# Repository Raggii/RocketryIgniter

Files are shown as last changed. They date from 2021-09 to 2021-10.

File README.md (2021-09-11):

# RocketryIgniter
To design and prototype a dual ignition system that can receive commands over UART and CANBUS. The device must be able to receive commands that arm and fire two separate but identical ignition circuits while also outputting its own system status. The design must attempt to be as compact as possible while also allowing for easy debugging.

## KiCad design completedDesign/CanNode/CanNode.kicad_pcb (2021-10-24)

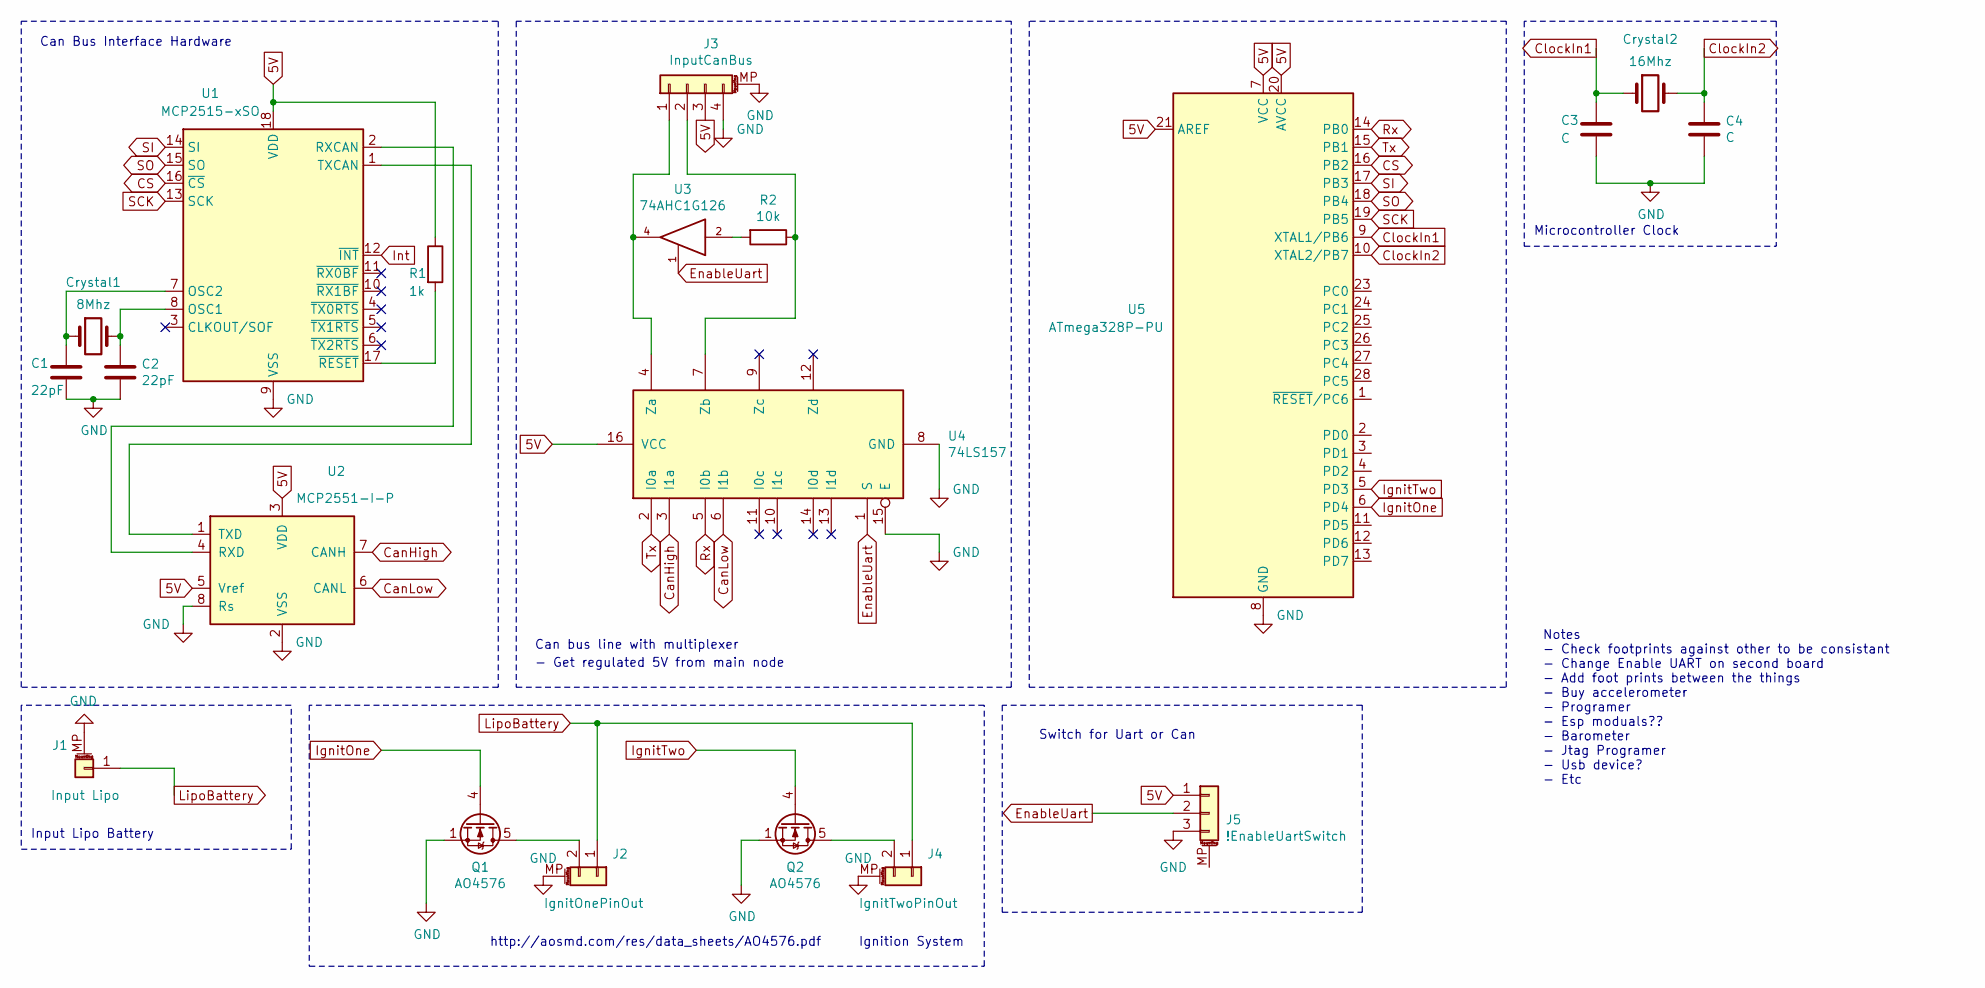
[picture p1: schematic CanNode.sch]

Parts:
C1, C2: 22pF; R_Axial_DIN0204_L3.6mm_D1.6mm_P2.54mm_Vertical
C3, C4: C; R_Axial_DIN0204_L3.6mm_D1.6mm_P2.54mm_Vertical
Crystal1: 8Mhz; Crystal_HC49-4H_Vertical
Crystal2: 16Mhz; Crystal_HC49-4H_Vertical
J1: Input Lipo; PinHeader_1x01_P2.00mm_Vertical
J2: IgnitOnePinOut; PinHeader_1x02_P2.00mm_Vertical
J3: InputCanBus; PinHeader_1x04_P2.00mm_Vertical
J4: IgnitTwoPinOut; PinHeader_1x02_P2.00mm_Vertical
J5: !EnableUartSwitch; PinHeader_1x03_P1.00mm_Vertical
Q1, Q2: AO4576; SOT-23-8_Handsoldering
R1: 1k; R_Axial_DIN0204_L3.6mm_D1.6mm_P5.08mm_Horizontal
R2: 10k; R_Axial_DIN0204_L3.6mm_D1.6mm_P5.08mm_Horizontal
U1: MCP2515-xSO; DIP-18_W7.62mm_LongPads
U2: MCP2551-I-P; DIP-8_W7.62mm
U3: 74AHC1G126; SOT65P210X110-5N
U4: 74LS157; DIP-16_W7.62mm_Socket_LongPads
U5: ATmega328P-PU; DIP-28_W7.62mm

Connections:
5V: J3.3, J5.1, R1.1, U1.18 (VDD), U2.3 (VDD), U2.5 (Vref), U4.16 (VCC), U5.7 (VCC), U5.20 (AVCC), U5.21 (AREF)
CS: U1.16 (~CS), U5.16 (PB2)
CanHigh: U2.7 (CANH), U4.3 (I1a)
CanLow: U2.6 (CANL), U4.6 (I1b)
ClockIn1: C3.1, Crystal2.1, U5.9 (XTAL1/PB6)
ClockIn2: C4.1, Crystal2.2, U5.10 (XTAL2/PB7)
EnableUart: J5.2, U3.1, U4.1 (S)
GND: C1.2, C2.2, C3.2, C4.2, J1.MP (MountPin), J2.MP (MountPin), J3.4, J3.MP (MountPin), J4.MP (MountPin), J5.3, Q1.1 (S), Q1.2 (S), Q1.3 (S), Q2.1 (S), Q2.2 (S), Q2.3 (S), U1.9 (VSS), U2.2 (VSS), U2.8 (Rs), U3.3 (GND), U4.8 (GND), U4.15 (E), U5.8 (GND), U5.22 (GND)
IgnitOne: Q1.4 (G), U5.6 (PD4)
IgnitTwo: Q2.4 (G), U5.5 (PD3)
Int: U1.12 (~INT)
LipoBattery: J1.1, J2.1, J4.1
unnamed: C1.1, Crystal1.1, U1.7 (OSC2)
unnamed: C2.1, Crystal1.2, U1.8 (OSC1)
unnamed: J2.2, Q1.5 (D)
unnamed: J3.1, U3.4, U4.4 (Za)
unnamed: J3.2, R2.1, U4.7 (Zb)
unnamed: J4.2, Q2.5 (D)
unnamed: R1.2, U1.17 (~RESET)
unnamed: R2.2, U3.2
unnamed: U1.1 (TXCAN), U2.1 (TXD)
unnamed: U1.2 (RXCAN), U2.4 (RXD)
Rx: U4.5 (I0b), U5.14 (PB0)
SCK: U1.13 (SCK), U5.19 (PB5)
SI: U1.14 (SI), U5.17 (PB3)
SO: U1.15 (SO), U5.18 (PB4)
Tx: U4.2 (I0a), U5.15 (PB1)
VCC: U3.5 (VCC)

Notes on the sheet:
Can Bus Interface Hardware
Can bus line with multiplexer
- Get regulated 5V from main node
Input Lipo Battery
Ignition System
http://aosmd.com/res/data_sheets/AO4576.pdf
Microcontroller Clock
Notes - Check footprints against other to be consistant - Change Enable UART on second board - Add foot prints between the things - Buy accelerometer - Programer - Esp moduals?? - Barometer - Jtag Programer - Usb device? - Etc
Switch for Uart or Can

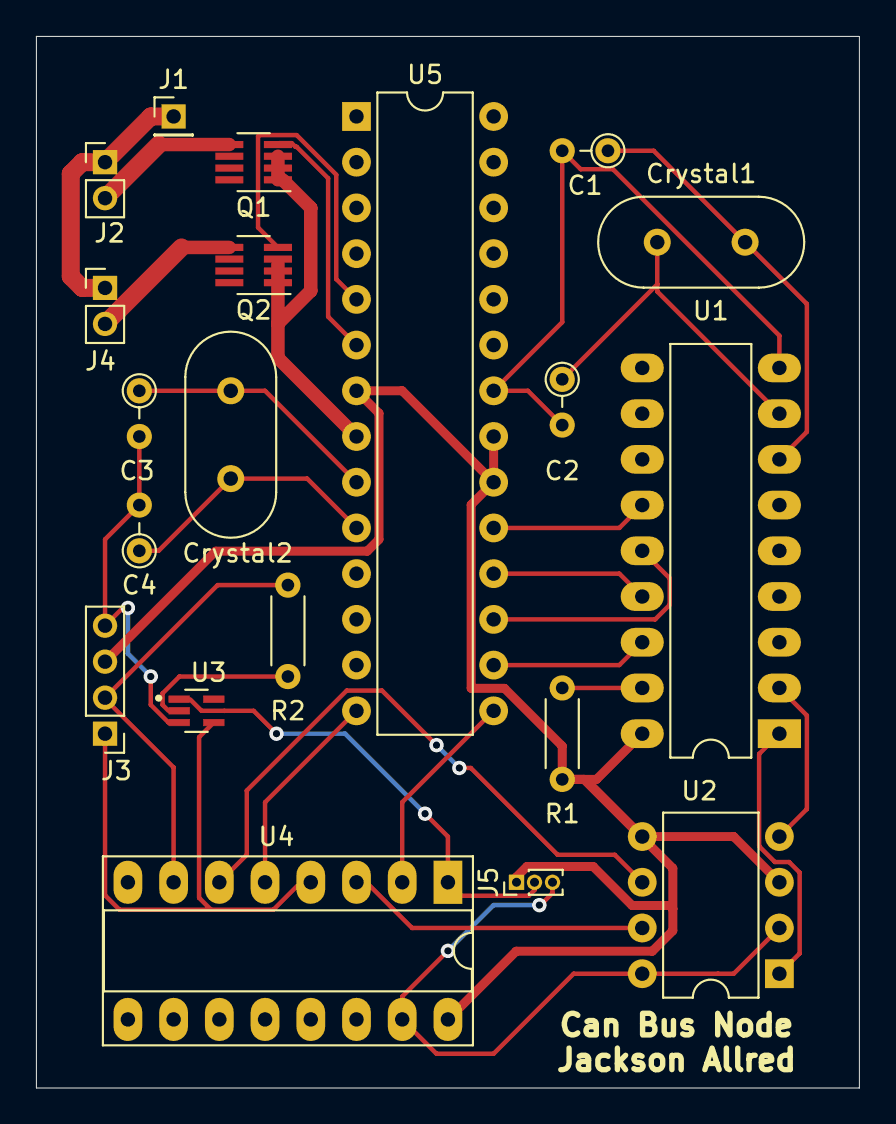
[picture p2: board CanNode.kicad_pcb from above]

Board: 2 copper layers, 45.7 x 58.4 mm, 20 parts (0 on the bottom side), 26 nets.

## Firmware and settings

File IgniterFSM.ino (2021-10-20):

#include <SoftwareSerial.h>

SoftwareSerial softSerial(4,5);

//States for the state machine
#define ERROR -1
#define IDLE 0 
#define ARMED 1
#define FIRING 2 
#define DISABLED 3 
#define LOCKOUT 4
#define TIMEOUT_TEN 10000
#define TIMEOUT_TWO 2000

//Received messages
#define ARM_IGNITER_ONE "01234567"
#define FIRE_IGNITER_ONE "76543210"
#define ARM_IGNITER_TWO "12345678"
#define FIRE_IGNITER_TWO "87654321"

//Pins for matches
#define FIRST_MATCH_PIN 2
#define SECOND_MATCH_PIN 3

//Variables
String receivedMessage;
String stateStringList[] = {"IDLE","ARMED","FIRING","DISABED","LOCKOUT"};

//Igniter variable struct
typedef struct igniterStateMachine {

  int currentState; 
  uint32_t timeOutCounter;
  bool continuity;
  bool arm;
  bool fire;
  int number;
  bool isTimedOut;
  bool stateUpdate;
  
} Igniter;

//Create an Igniter Struct
Igniter* initIgniter(int number){

  Igniter * returnIgniter = (Igniter *)malloc(sizeof(Igniter) * 2);
  returnIgniter->currentState = IDLE;
  returnIgniter->continuity = true;
  returnIgniter->timeOutCounter = 0;
  returnIgniter->arm = false;
  returnIgniter->fire = false;
  returnIgniter->number = number;
  returnIgniter->isTimedOut = false;
  returnIgniter->stateUpdate = false;
  return returnIgniter;
  
}

void serialOutMsg(String message) {

    Serial.println(message);
    softSerial.println(message);
  
}

void printIgniterState(Igniter* igniter){

  String number = String(igniter->number);
  String arm = String(igniter->arm);
  String fire = String(igniter->fire);
  String timeout = String(igniter->isTimedOut);

  Serial.println("Igniter " + number + "\nState is: " + stateStringList[igniter->currentState] + 
                "\nArm Boolean: " + arm + "\nFire Boolean: " + fire + "\nTime Out: " + timeout+ "\n");
  
}

/** Changes the state of the state machine if in IDLE state to ARMED
*   Gets called if armed boolean changes
**/
int armFunction(Igniter* igniter) {
  if(igniter->arm) {
    if(igniter->currentState == IDLE && !igniter->fire)
      igniter->currentState = ARMED;
      //Start 10 Second timer and if fails then sets Arm and Fire to disabled
      igniter->timeOutCounter = millis(); // Snap shot of time when state changed
      
  } else {
     //serialOutMsg("IS NOT TRUE");
     if(igniter->currentState == ARMED){
        igniter->currentState = IDLE;
        //Resets the timer when changes state
        igniter->timeOutCounter = 0;
     }
  }

  return -1;
}
//Changes the state of the state machine if in ARMED state to FIRESTATE
int fireFunction(Igniter* igniter) {

  if(igniter->fire) {
    if(igniter->currentState == ARMED && igniter->arm) {
      igniter->currentState = FIRING;
      //Resets the timer when changes state
      igniter->timeOutCounter = millis();
      
      //Sets pin to Disabled for
      
    } 
  }
 return -1; 
}


/** Changes the state of variables in the Igniter given depending on the message input
 *  Also used to toggle between on and off
 *   returns NULL on fail 
*/
void updateState(String receivedMessage, Igniter* igniter) {
  if(igniter->continuity && !igniter->isTimedOut) {
    if(igniter->number == 1){
      if(receivedMessage == ARM_IGNITER_ONE) {
        //Arming true
        if(igniter->currentState == !LOCKOUT) {
          if(igniter->arm) {
              igniter->arm = false;
              serialOutMsg("First Igniter Arm Pin Deactivated");
          }else {
            igniter->arm = true;
            serialOutMsg("First Igniter Arm Pin Activated"); 
          }
        } else {
           //Is locked out  
            
        }
        igniter->stateUpdate = true;

      }else if(receivedMessage == FIRE_IGNITER_ONE) {
        //Firing true
        if(igniter->fire) {
          igniter->fire = false; 
          serialOutMsg("First Igniter Fire Pin Deactivated");
        } else {
          igniter->fire = true; 
          serialOutMsg("First Igniter Fire Pin Activated");  
        }
        
        igniter->stateUpdate = true;
            
      }  
    }else if(igniter->number == 2){
      if(receivedMessage == ARM_IGNITER_TWO) {
         //Arming true
         if(igniter->arm) {
            igniter->arm = false;
            serialOutMsg("Second Igniter Arm Pin Deactivated");
        }else {
          igniter->arm = true;
          serialOutMsg("Second Igniter Arm Pin Activated"); 
        }
         igniter->stateUpdate = true;
         
       } else if(receivedMessage == FIRE_IGNITER_TWO) {
        //Firing true
        if(igniter->fire) {
          igniter->fire = false; 
          serialOutMsg("Second Igniter Fire Pin Deactivated");
        } else {
          igniter->fire = true; 
          serialOutMsg("Second Igniter Fire Pin Activated");  
        }
        igniter->stateUpdate = true;
       } //else return NULL;
    }
    
  } else {
    //Continuity is not connected so dont update anystate
    if(igniter->isTimedOut) {
        serialOutMsg("Timed out please wait");
    } else {
      serialOutMsg("Continuity check has failed, Please try again");
    }
    
  }
  if(!igniter->arm && !igniter->fire) {
      igniter->currentState = IDLE;
      serialOutMsg("First Igniter Set Back To Idle"); 
  }
  return NULL;
}

void disableIgnitor(Igniter* igniter) {

    igniter->isTimedOut = true;
    igniter->timeOutCounter = millis(); // Start next timer for lock out
    igniter->currentState = DISABLED;
    serialOutMsg("Igniter " + String(igniter->number) + " has been disabled for 10 seconds");
  
}

void timeOutIgniter(Igniter * igniter) {
  

    igniter->timeOutCounter = 0; // Resets counter
    igniter->currentState = LOCKOUT;
    serialOutMsg("Igniter " + String(igniter->number) + " has been Locked Out, Set arm and fire to false to continue");
    igniter->isTimedOut = false;
  
}

void lockoutHandler(Igniter* igniter) {

    if(igniter->currentState == ARMED) {
      //If in armed state check for timer
      //serialOutMsg(String(millis() - firstIgniter->timeOutCounter));
      if((millis() - igniter->timeOutCounter) >= TIMEOUT_TEN) {
        
        disableIgnitor(igniter);
          
      }
    } else if(igniter->currentState == DISABLED) {

        if((millis() - igniter->timeOutCounter) >= TIMEOUT_TEN) {
          
          timeOutIgniter(igniter);
        }      
    } else if(igniter->currentState == FIRING) {

      if((millis() - igniter->timeOutCounter) >= TIMEOUT_TWO) {
          
           disableIgnitor(igniter);
      }
  }
}


Igniter* firstIgniter = initIgniter(1);
Igniter* secondIgniter = initIgniter(2);

void setup() {

  softSerial.begin(9600); // WILL HAVE TO CHANGE FOR CAN
  Serial.begin(9600); // WILL HAVE TO CHANGE FOR CAN
  pinMode(FIRST_MATCH_PIN, OUTPUT);
  pinMode(SECOND_MATCH_PIN, OUTPUT);
  //Also add adc reading for this
}


void loop() {


  //Only change state when something is read
  if(softSerial.available() > 0){
    
    //Stores inputted string into a buffer
    receivedMessage = softSerial.readString();

    //Only if received 8 bytes of information 
    if(receivedMessage.length() == 8) {
      //Updates the state varaibles for the Igniters 
      updateState(receivedMessage, firstIgniter);
      updateState(receivedMessage, secondIgniter);

      //If there was an updated state value then the stateUpdate will be called

      /**To Do:
       * Add timing circuits to change from armed and firing to Disabled.
       * On fire change update the pin for 2 seconds
       * Always output current state of both igniters and battery voltage
       */
      
      if(firstIgniter->stateUpdate) {
          firstIgniter->stateUpdate == false;
          armFunction(firstIgniter);
          fireFunction(firstIgniter);
          
      }
      if(secondIgniter->stateUpdate) {
          secondIgniter->stateUpdate == false;
          armFunction(secondIgniter);
          fireFunction(secondIgniter);

      }
    }
    //softSerial.println(receivedMessage.length());
    printIgniterState(firstIgniter);
    printIgniterState(secondIgniter);
  }

  lockoutHandler(firstIgniter);
  lockoutHandler(secondIgniter);
}

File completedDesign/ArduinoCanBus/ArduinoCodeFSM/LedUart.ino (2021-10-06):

int pinParashute = 7;
int pinIgnition = 6;

void setup() {
  // put your setup code here, to run once:
  pinMode(pinParashute, OUTPUT);
  pinMode(pinIgnition, OUTPUT);

}

void loop() {
  // put your main code here, to run repeatedly:

  digitalWrite(pinParashute, HIGH);
  digitalWrite(pinIgnition, HIGH);

}

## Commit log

2021-09-12 added notes about STM microcontrollers as well as Uart communication \n in future add CanBus stuff
2021-10-03 Ideas for testing voltage measurement and regulator
    voltage measurement and regulation
2021-10-03 Shopping lost for canbus items
2021-10-03 The Circuit
    Wow speeelll right
    [RocketIgniter300.kicad_pcb, RocketIgniter300.sch]
2021-10-03 Updated schematic
    [RocketIgniter300.sch]
2021-10-06 Added test arduino code
2021-10-07 Dan doesnt know how to git hub
    [RocketIgniter300.kicad_pcb, RocketIgniter300.sch]
2021-10-09 Added Second board
    A rough board
    [CanNode.kicad_pcb, CanNode.sch]
2021-10-11 Updated the foot prints
    Added notes also
    [CanNode.sch]
2021-10-12 Updated the schematic somre more
    Hope u can get it finished tomorrow!!
    [CanNode.kicad_pcb, CanNode.sch]
2021-10-24 Final Upload
    [CanNode.kicad_pcb, CanNode.sch]
